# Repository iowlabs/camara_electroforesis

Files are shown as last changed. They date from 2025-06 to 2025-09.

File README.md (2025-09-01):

# Cámara electroforésis

Este proyecto tiene como objetivo el diseño de una cámara de electroforesis de bajo costo y fácil acceso, ideal para entornos educativos, laboratorios escolares,  iniciativas de ciencia ciudadana, equipamientos de bajo costo o laboratorios portátiles. El sistema completo incluye tanto la cámara donde se realiza la separación de moléculas como una fuente de poder casera que permite aplicar el voltaje necesario para el experimento.

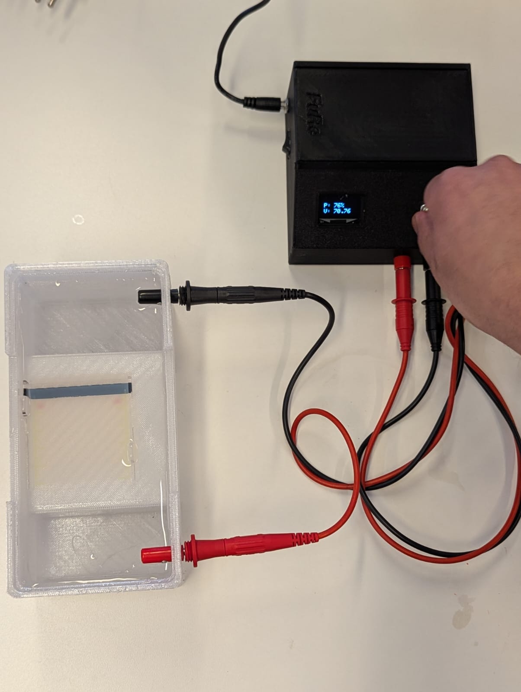
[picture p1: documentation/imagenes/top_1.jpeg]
Cámara de electróforesis


El diseño y la implementación de este proyecto están fuertemente inspirados en la documentación proporcionada por IORodeo, quienes han compartido detalladamente cómo construir sistemas de electroforesis caseros. En particular, se han seguido y adaptado los siguientes recursos:

- [Cámara de electroforesis - Instructables](https://www.instructables.com/Gel-electrophoresis-system-mini/)
- [Fuente de poder - Instructables](https://www.instructables.com/Gel-electrophoresis-power-supply/)

Este repositorio prone un nuevo diseño orientado a consolidar y empaquetar el proceso de fabricación de los componentes por medio de nuevos diseños basados principalmente en impresión 3D. De este modo se consolida la información, archivos de diseño, materiales necesarios y las mejoras propuestas por iow Labs con la intención de facilitar la replicabilidad y su uso por parte de otras personas o instituciones interesadas en el uso de tecnologías abiertas en la ciencia.

---
# Licencias
Todos los archivos involucrados en este proyecto se encuentran bajo licencias abiertas, para su replicabilidad y comercialización.

| Tipo de archivo | Licencia |
| --- |  ----- |
| Electronica 	  |  CERN-OHL-S-2.0 |
| Software y firmware |  GPL-3.0-or-later|
| Diseños 3D |  CERN-OHL-S-2.0 |
| Archivos de documentación | CC-BY-SA-4.0 |

---

# Cámara

En este diseño se propone un modelo de cámara impreso totalmente, como una pieza continua. De este modo, se facilita el proceso de fabricación evitando trabajar con acrílico y las complicaciones que esto implica.

## Materiales

Los tanques para la electróforesis habitualmente se fabrican con acrílico, sin embargo el proceso de cortado y pegado suele ser dificil de gestionar ya que requiere habilidades manuales princilamnte debido a que involucra la manipulación de cloroformo.

Para evitar esto, se implementó una alternativa basada en impresión 3D. Para replicar las características del acrílico se evaluaron diferentes materialidades y metodologías. Finalmente, se optó por imprimir el cuerpo del tanque en PETG para garantizar el buen desempeño en altas temperaturas y para garantizar la impermeabilidad, se optó por aplicarle una capa de resina epoxyca al interior. La tapa se realiza en un solo corte acrílico, para garantizar la transparencia.   

| Pieza 	| Material | Archivo |
| --- | --- | --- |
| Tanque 	|  PETG | [tanque_V2.stl](https://github.com/iowlabs/camara_electroforesis/blob/main/3d%20models/tank_v2.stl) |
| Tapa		| Acrílico | [tapa_V2.stl](https://github.com/iowlabs/camara_electroforesis/blob/main/3d%20models/tapa_v2.stl) |

### Instrucciones de fabricación

## Lista de materiales

| N | Componente 	| Cantidad | Comentario |
|---|---|---|---|
| 1 | Tanque |  1 | |
| 2 | Tapa |  1 | |
| 3 | Conectores banana |  2 | Tipo macho |
| 4 | Electrodos de pt |  2 | arpox 20cm de cable de 0.01'' de platino |

## Instrucciones de armado

---

# Fuente de poder

Para implementar la fuente se diseñó una PCB que integre los componentes considerando en su mayoría componentes SMD. Esta PCB consiste en la implementación de un conversor DC/DC del tipo chopper bust. Este diseño se basa en el integrado MAX117 y la topología utilizada se encuentra detallada en los siguientes documentos 3,4,5
Esta topología es utilizada ampliamente por diferentes proyectos como el Open Drop o la misma fuente de electroforesis de IORodeo. Adicionalmente se consideró agregar un microcontrolador de la familia ESP32S3 para agregar nuevas funcionalidades al diseño y poder considerar en una implementación futura las capacidades de conectividad para montar  una red Lab on a Web que permita controlar todo el laboratorio de forma centralizada y remota.

El esquemático completo se entrega en la siguiente imagen.

Esquemático de la PCB

A continuación se entregan imágenes de las visualizaciones 3D del render de la PCB

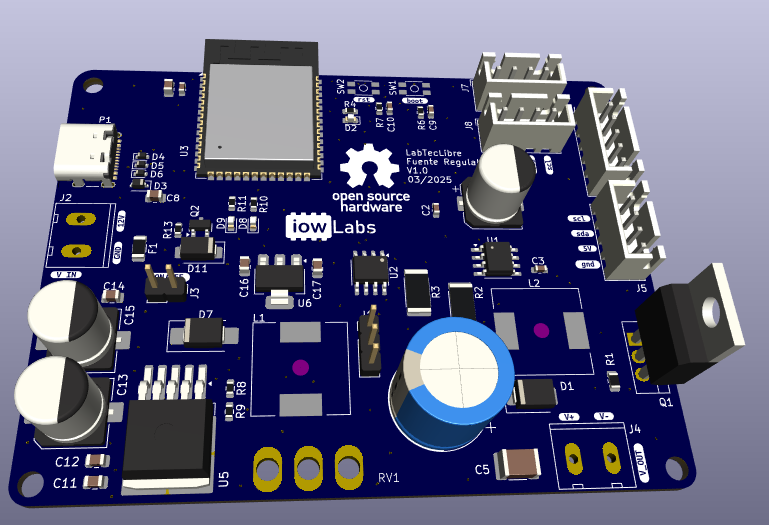
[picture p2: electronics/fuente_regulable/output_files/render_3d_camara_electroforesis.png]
PCB 3D


La PCB considera la integración de una interfaz de usuario implementada por medio de un rotary switch y una pantalla OLED con el objetivo de visualizar el valor actual de voltaje de salida.

Para integrar todos los componentes de forma segura se ha diseñado un casing 3D impreso en PLA.

### Archivos de fabricación
Los archivos de fabricación de la PCB se encuentran disponibles en formato ZIP en el directorio de [archivos de salida](https://github.com/iowlabs/camara_electroforesis/tree/main/electronics/fuente_regulable/output_files) listos para ser enviados a fabricación.

Para el casing, los archivos se encuentran en la carpeta de modelos 3D.

| Pieza 	| Material | Archivo |
| --- | --- | --- |
| Tapa superior 	|  PLA | [fure_tapa.step](https://github.com/iowlabs/camara_electroforesis/blob/main/3d%20models/fure_tapa.step) |
| Cara frontal		| PLA | [fure_cara.step](https://github.com/iowlabs/camara_electroforesis/blob/main/3d%20models/fure_cara.step) |
|  Base		| PLA | [fure_base.step](https://github.com/iowlabs/camara_electroforesis/blob/main/3d%20models/fure_base.step) |

### BOM de PCB
La lista de los componentes se encuentra disponible en el archivo BOM  [fuente_regulable_bom.csv](https://github.com/iowlabs/camara_electroforesis/blob/main/electronics/fuente_regulable/output_files/fuente_regulable_bom.csv), como referencia se consideran de LCSC.

### Lista de materiales para la fuente regulable.

| N | Componente 	| Cantidad | Comentario |
|---|---|---|---|
| 1 | FuRe PCB |  1 | PCB by iow Labs |
| 2 | Conectores banana|  2 |  Tipo hembra  |
| 3 | Cables banana |  2 | Tipo macho - hembra |
| 4 | Switch on/off |  1 |  |
| 5 | Rotary encoder switch |  1 |  |
| 6 | Jack DC |  1 |  |
| 7 | Pantalla OLED |  1 |  |
| 8 | case - superior |  1 | Pieza impresa |
| 9 | case - frontal |  1 | Pieza impresa |
| 10 | case - base |  1 | Pieza impresa |
| 11 | Fuente de 12V |  1 | Al menos 1A (12W) |
| 12 | Tornillos M3 |  6 | Al menos 12mm |
| 13 | Tuercas M3 |  4 | |
| 14 | Cable AWG 20 |  - | Para conexiones internas |
| 15 | Cable AWG 26 - 4 wires |  1 | Cable de la pantalla OLED |
| 16 | Cable AWG 26 - 5 wires |  1 | Cable del rotary encoder |

### Firmware

El firmware se puede encontrar en el directorio [firmware](https://github.com/iowlabs/camara_electroforesis/tree/main/firmware). Esta escrito en el framwork de arduino. Para cargarlo correctamente es necesario configurar en el IDE de arduino la placa ESP32-S3. Para esto se puede usar el modelo ESP32-S3-DEV-Kit.

El código subido implementa una interfaz sencilla entre el rotary encoder y el voltaje de salida que se configura en el módulo MAX117 por medio de un potenciomentro digital configurado por SPI.

Todas las bibliotecas utilizadas se encuentran dentro del repositorio oficial de arduino.

## Instrucciones de ensamblado

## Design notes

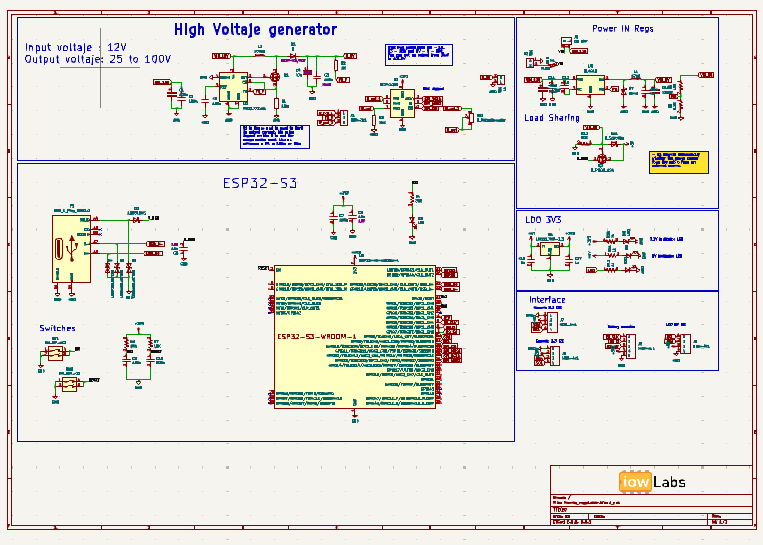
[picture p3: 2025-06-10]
electronics/fuente_regulable/output_files/fuente_electroforesis_esquematico.png

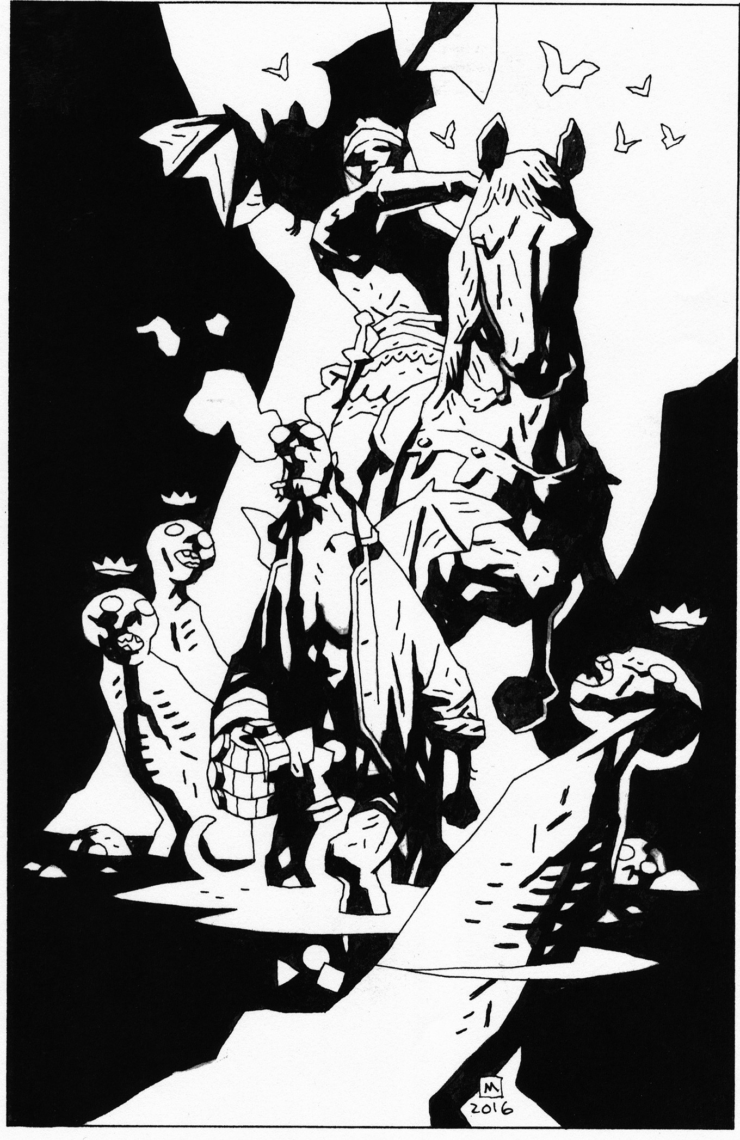
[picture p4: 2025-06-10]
mike-mignola-artwork-thought.jpg

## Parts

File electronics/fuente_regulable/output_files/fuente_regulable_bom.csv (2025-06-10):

Reference | Value | Footprint | Qty | DNP
C1 | 100u | Capacitor_SMD:C_1206_3216Metric | 1 | 5 |  | C445063
C2,C3,C7,C9,C10 | 100n | Capacitor_SMD:C_0603_1608Metric | 5 | 25 |  | C1591
C4 | 47u | Capacitor_SMD:C_1206_3216Metric | 1 | 5 |  | C2837971
C5 | 100n | Capacitor_SMD:C_1812_4532Metric | 1 | 5 |  | C106148
C6,C8 | 10u | Capacitor_SMD:C_0805_2012Metric | 2 | 10 |  | C386019
C11,C12,C14,C16,C17 | 1u | Capacitor_SMD:C_0805_2012Metric | 5 | 25 |  | C215803
C13 | 220uF | Capacitor_SMD:CP_Elec_8x10.5 | 1 | 5 |  | C3353
C15 | 330uF | Capacitor_SMD:CP_Elec_8x10.5 | 1 | 5 |  | C3353
D1 | D | Diode_SMD:D_SMB | 1 | 5 |  | C145321
D2,D8,D9,D10 | LED | LED_SMD:LED_0603_1608Metric | 4 | 20
D3 | 1N5819WS | Diode_SMD:D_SOD-323 | 1 | 5 |  | C82544
D4,D5,D6 | LESD5D5.0CT1G | Diode_SMD:D_SOD-523 | 3 | 15 | 637-ESD5B5V0WT | C5246195
D7 | B540 | Diode_SMD:D_SMB_Handsoldering | 1 | 5 | 750-ACDBB540-HF | C3019736
D11 | D_Schottky | Diode_SMD:D_SMA | 1 | 5 |  | C85098
F1 | FUSE | Fuse:Fuse_1206_3216Metric | 1 | 5 |  | C41367231
J1 | HDR-3x1 | Connector_JST:JST_XH_B4B-XH-A_1x04_P2.50mm_Vertical | 1 | 5
J2,J4 | VIN | IoWLabsConnectors:Tb-2x1-5p-TH-V | 2 | 10
J3 | ON OFF | Connector_PinHeader_2.54mm:PinHeader_1x02_P2.54mm_Vertical | 1 | 5
J5,J7,J8 | HDR-4x1 | Connector_JST:JST_XH_B4B-XH-A_1x04_P2.50mm_Vertical | 3 | 15
J6 | HDR-5x1 | Connector_JST:JST_XH_B5B-XH-A_1x05_P2.50mm_Vertical | 1 | 5
L1 | 47uH | Inductor_SMD:L_12x12mm_H8mm | 1 | 5 |  | C2929502
L2 | 100uH | Inductor_SMD:L_12x12mm_H8mm | 1 | 5 |  | C7431084
P1 | USB_C_Plug_USB2.0 | Connector_USB:USB_C_Receptacle_GCT_USB4105-xx-A_16P_TopMnt_Horizontal | 1 | 5 | 179-UJ20CHC4SMTTR | C165948
Q1 | Q_NMOS_Depletion_GDS | Package_TO_SOT_SMD:TO-220 | 1 | 5 |  | C34373758
Q2 | Q_PMOS_GSD | Package_TO_SOT_SMD:SOT-23 | 1 | 5 | 512-FDN338P | C518789
R1 | 10m | Resistor_SMD:R_2512_6332Metric | 1 | 5 |  | C2934081
R2 | 1M | Resistor_SMD:R_2512_6332Metric | 1 | 5 |  | C346106
R3 | 15K | Resistor_SMD:R_2512_6332Metric | 1 | 5 |  | C5200562
R4 | 330 | Resistor_SMD:R_0603_1608Metric | 1 | 5
R6,R7,R8,R13 | 10K | Resistor_SMD:R_0603_1608Metric | 4 | 20
R9 | 3.3K | Resistor_SMD:R_0603_1608Metric | 1 | 5 |  | C309653
R10,R11,R12 | 1k | Resistor_SMD:R_0603_1608Metric | 3 | 15
RV1 | R_Potentiometer | IoWLabs:PDB18 - Rotary Potentiometer | 1 | 5
SW1,SW2 | SW_DIP_x02 | IoWLabs:SMD_SWITCH | 2 | 10 | 688-SKTHACE010 | C128941
U1 | MAX1771xSA | Package_SO:SO-8_3.9x4.9mm_P1.27mm | 1 | 5 | 700-MAX1771CSAT | C407903
U2 | MCP41050 | Package_SO:SOIC-8_3.9x4.9mm_P1.27mm | 1 | 5 | 579-MCP41050-I/SN | C124138
U3 | ESP32-S3-WROOM-1 | RF_Module:ESP32-S3-WROOM-1 | 1 | 5 | 356-ESP32-S3WROOM1N8 | C2913205
U5 | XL4015 | Package_TO_SOT_SMD:TO-263-5_TabPin3 | 1 | 5 |  | C51661
U6 | AP2112K-3.3 | Package_TO_SOT_SMD:SOT-23-5 | 1 | 5 |  | C129334

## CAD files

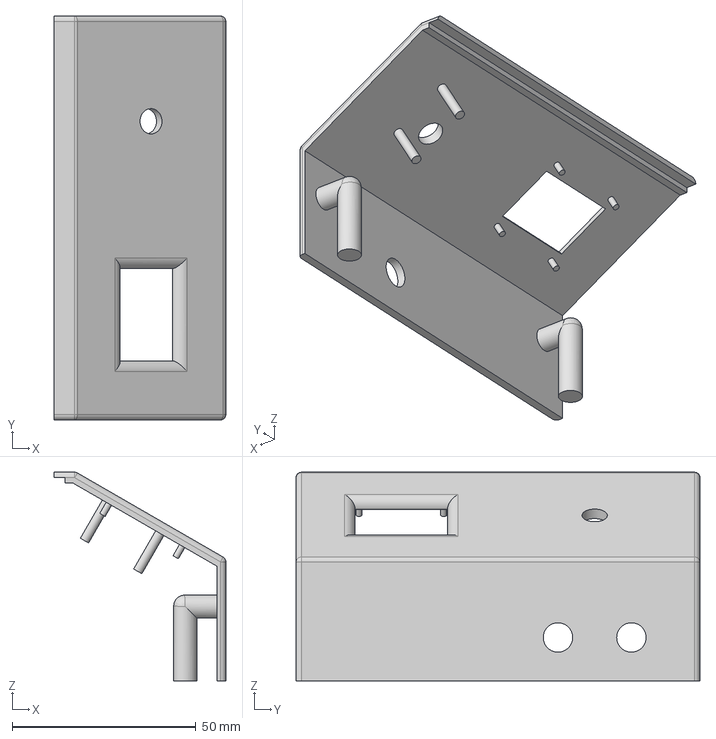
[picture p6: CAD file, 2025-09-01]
3d models/fure_cara.step
46.8 x 110.0 x 56.8 mm

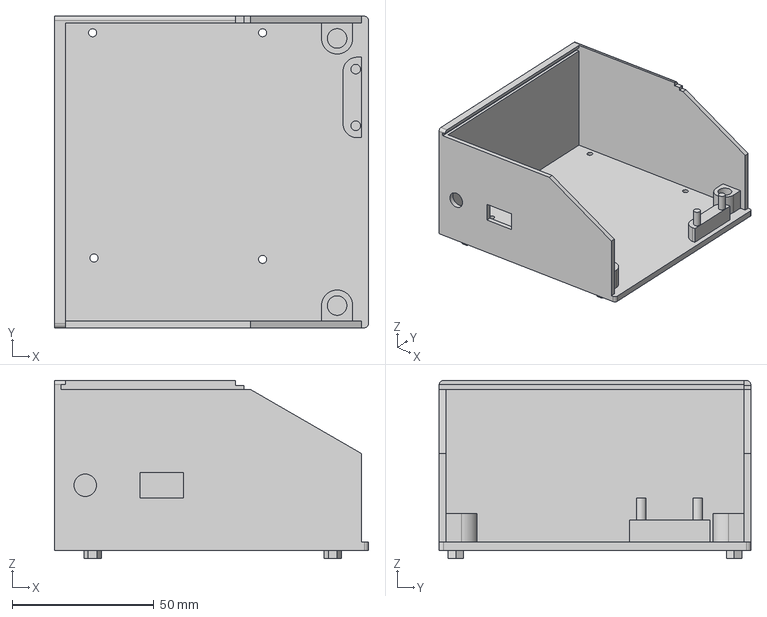
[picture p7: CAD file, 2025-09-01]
3d models/fure_base.step
110.9 x 110.0 x 62.9 mm

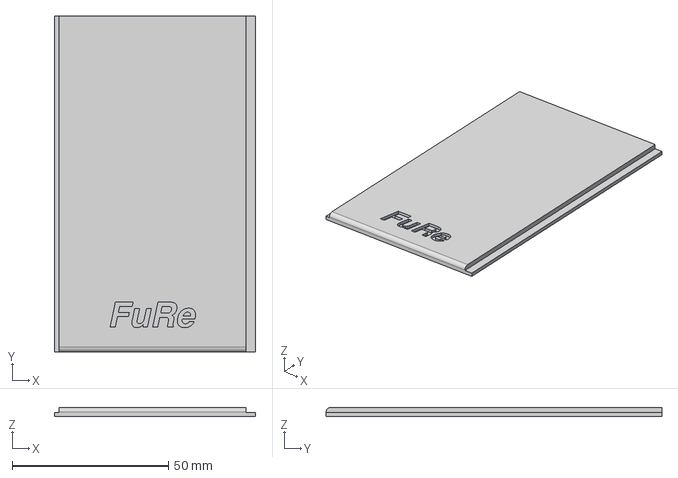
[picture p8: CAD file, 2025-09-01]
3d models/fure_tapa.step
64.3 x 107.5 x 3.00 mm

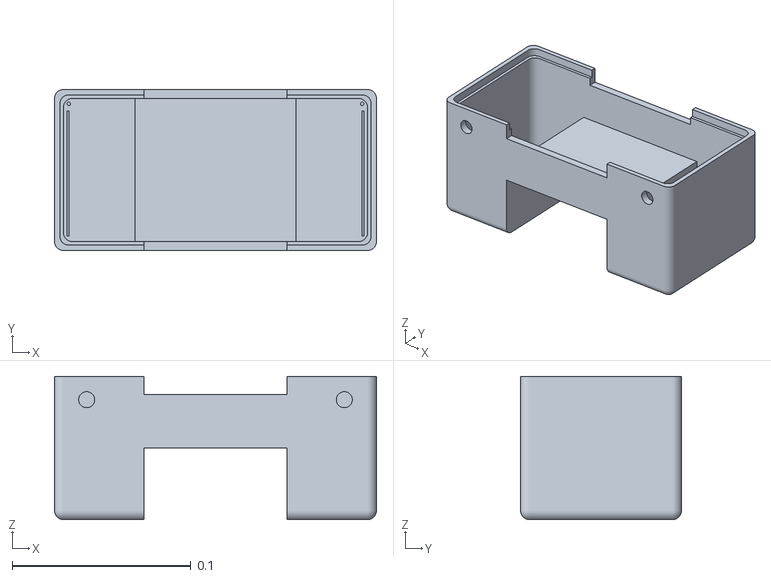
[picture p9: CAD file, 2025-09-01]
3d models/tank_v2.stl
0.18 x 0.09 x 0.08

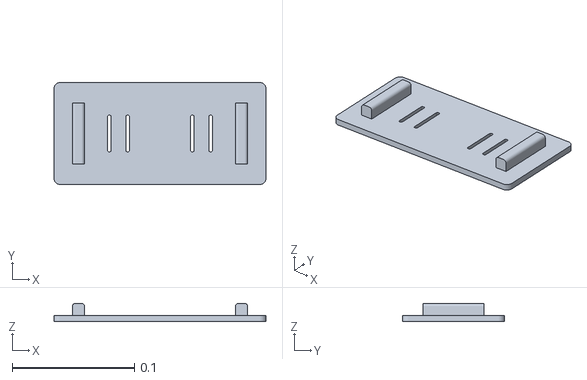
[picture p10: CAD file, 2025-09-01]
3d models/tapa_v2.stl
0.174 x 0.0835 x 0.015

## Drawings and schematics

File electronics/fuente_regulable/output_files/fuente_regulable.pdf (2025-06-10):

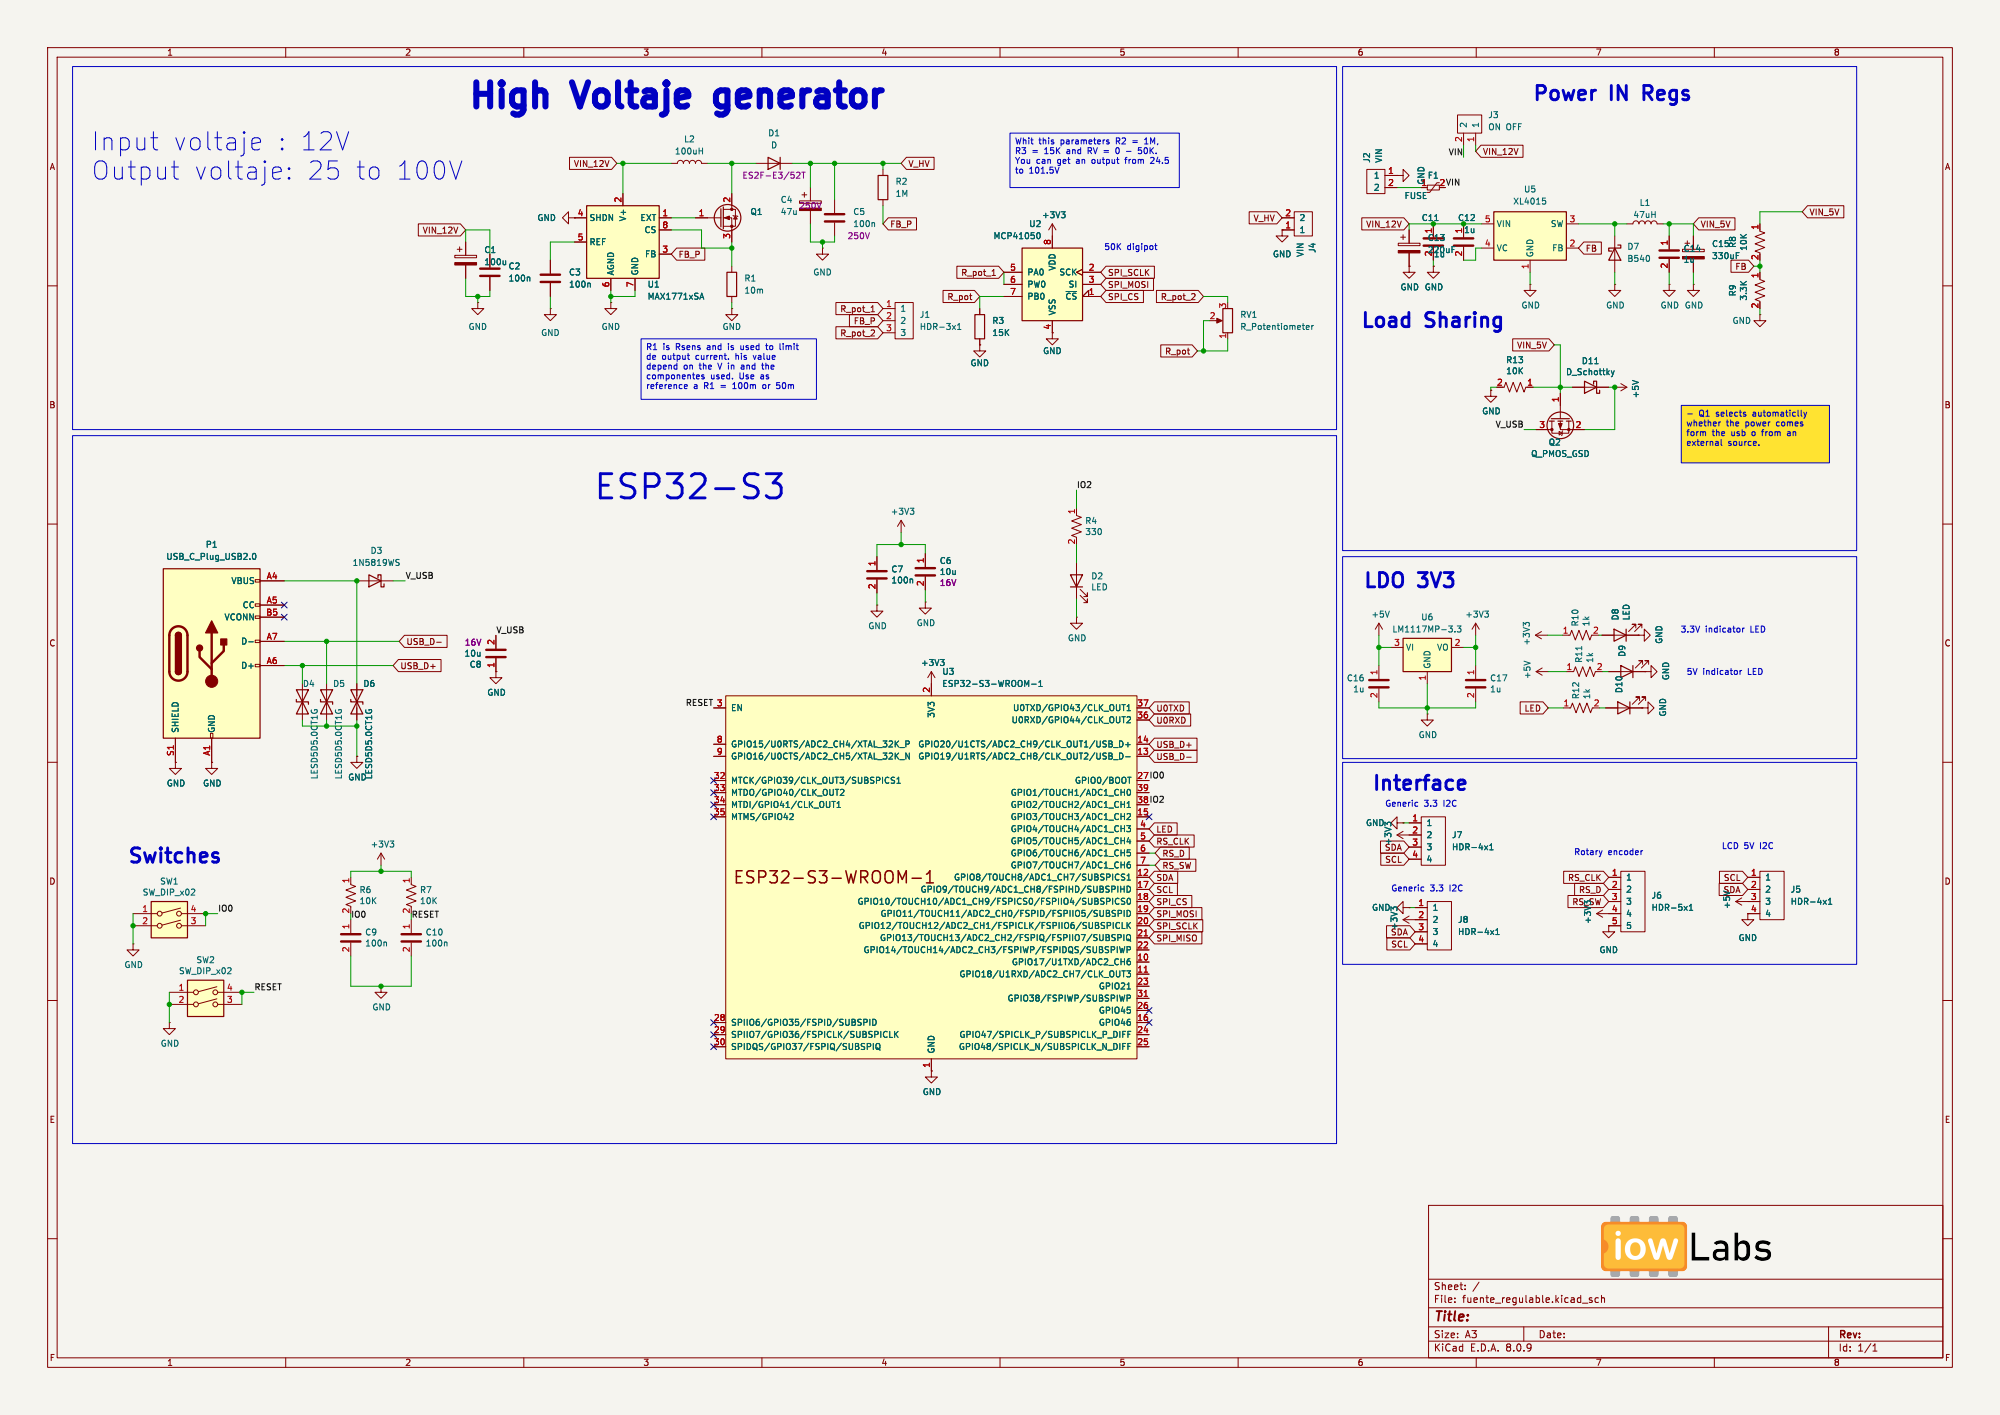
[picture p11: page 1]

1 FB 2 SW 3 VC 4 VIN 5 U5 XL4015

2 FB 3 SHDN 4 REF 5 AGND

depend on the V in and the

- Q1 selects automaticlly whether the power comes

form the usb o from an

1 2 P1 USB_C_Plug_USB2.0 GND A1 VBUS A4 CC A5 D+ A6 D- A7 VCONN B5 SHIELD S1

2 GPIO12/TOUCH12/ADC2_CH1/FSPICLK/FSPIIO6/SUBSPICLK 20 GPIO13/TOUCH13/ADC2_CH2/FSPIQ/FSPIIO7/SUBSPIQ 21 GPIO14/TOUCH14/ADC2_CH3/FSPIWP/FSPIDQS/SUBSPIWP 22 GPIO21 23 GPIO47/SPICLK_P/SUBSPICLK_P_DIFF 24 GPIO48/SPICLK_N/SUBSPICLK_N_DIFF 25 GPIO45 26 GPIO0/BOOT 27 SPIIO6/GPIO35/FSPID/SUBSPID 28 SPIIO7/GPIO36/FSPICLK/SUBSPICLK 29 EN 3 SPIDQS/GPIO37/FSPIQ/SUBSPIQ 30 GPIO38/FSPIWP/SUBSPIWP 31 MTCK/GPIO39/CLK_OUT3/SUBSPICS1 32 MTDO/GPIO40/CLK_OUT2 33 MTDI/GPIO41/CLK_OUT1 34 MTMS/GPIO42 35 U0RXD/GPIO44/CLK_OUT2 36 U0TXD/GPIO43/CLK_OUT1 37 GPIO2/TOUCH2/ADC1_CH1 38 GPIO1/TOUCH1/ADC1_CH0 39 GPIO4/TOUCH4/ADC1_CH3 4 GPIO5/TOUCH5/ADC1_CH4 5 GPIO6/TOUCH6/ADC1_CH5 6 GPIO7/TOUCH7/ADC1_CH6 7 GPIO15/U0RTS/ADC2_CH4/XTAL_32K_P 8 GPIO16/U0CTS/ADC2_CH5/XTAL_32K_N 9 U3ESP32-S3-WROOM-1 +3V3 GND GND

2 GPIO12/TOUCH12/ADC2_CH1/FSPICLK/FSPIIO6/SUBSPICLK 20 GPIO13/TOUCH13/ADC2_CH2/FSPIQ/FSPIIO7/SUBSPIQ 21 GPIO14/TOUCH14/ADC2_CH3/FSPIWP/FSPIDQS/SUBSPIWP 22 GPIO21 23 GPIO47/SPICLK_P/SUBSPICLK_P_DIFF 24 GPIO48/SPICLK_N/SUBSPICLK_N_DIFF 25 GPIO45 26 GPIO0/BOOT 27 SPIIO6/GPIO35/FSPID/SUBSPID 28 SPIIO7/GPIO36/FSPICLK/SUBSPICLK 29 EN 3 SPIDQS/GPIO37/FSPIQ/SUBSPIQ 30 GPIO38/FSPIWP/SUBSPIWP 31 MTCK/GPIO39/CLK_OUT3/SUBSPICS1 32 MTDO/GPIO40/CLK_OUT2 33 MTDI/GPIO41/CLK_OUT1 34 MTMS/GPIO42 35 U0RXD/GPIO44/CLK_OUT2 36 U0TXD/GPIO43/CLK_OUT1 37 GPIO2/TOUCH2/ADC1_CH1 38 GPIO1/TOUCH1/ADC1_CH0 39 GPIO4/TOUCH4/ADC1_CH3 4 GPIO5/TOUCH5/ADC1_CH4 5 GPIO6/TOUCH6/ADC1_CH5 6 GPIO7/TOUCH7/ADC1_CH6 7 GPIO15/U0RTS/ADC2_CH4/XTAL_32K_P 8 GPIO16/U0CTS/ADC2_CH5/XTAL_32K_N 9 +3V3 GND

1 GPIO17/U1TXD/ADC2_CH6 10 GPIO18/U1RXD/ADC2_CH7/CLK_OUT3 11 GPIO8/TOUCH8/ADC1_CH7/SUBSPICS1 12 GPIO19/U1RTS/ADC2_CH8/CLK_OUT2/USB_D- 13 GPIO20/U1CTS/ADC2_CH9/CLK_OUT1/USB_D+ 14 GPIO3/TOUCH3/ADC1_CH2 15 GPIO46 16 GPIO9/TOUCH9/ADC1_CH8/FSPIHD/SUBSPIHD 17 GPIO10/TOUCH10/ADC1_CH9/FSPICS0/FSPIIO4/SUBSPICS0 18 GPIO11/TOUCH11/ADC2_CH0/FSPID/FSPIIO5/SUBSPID 19 3V3

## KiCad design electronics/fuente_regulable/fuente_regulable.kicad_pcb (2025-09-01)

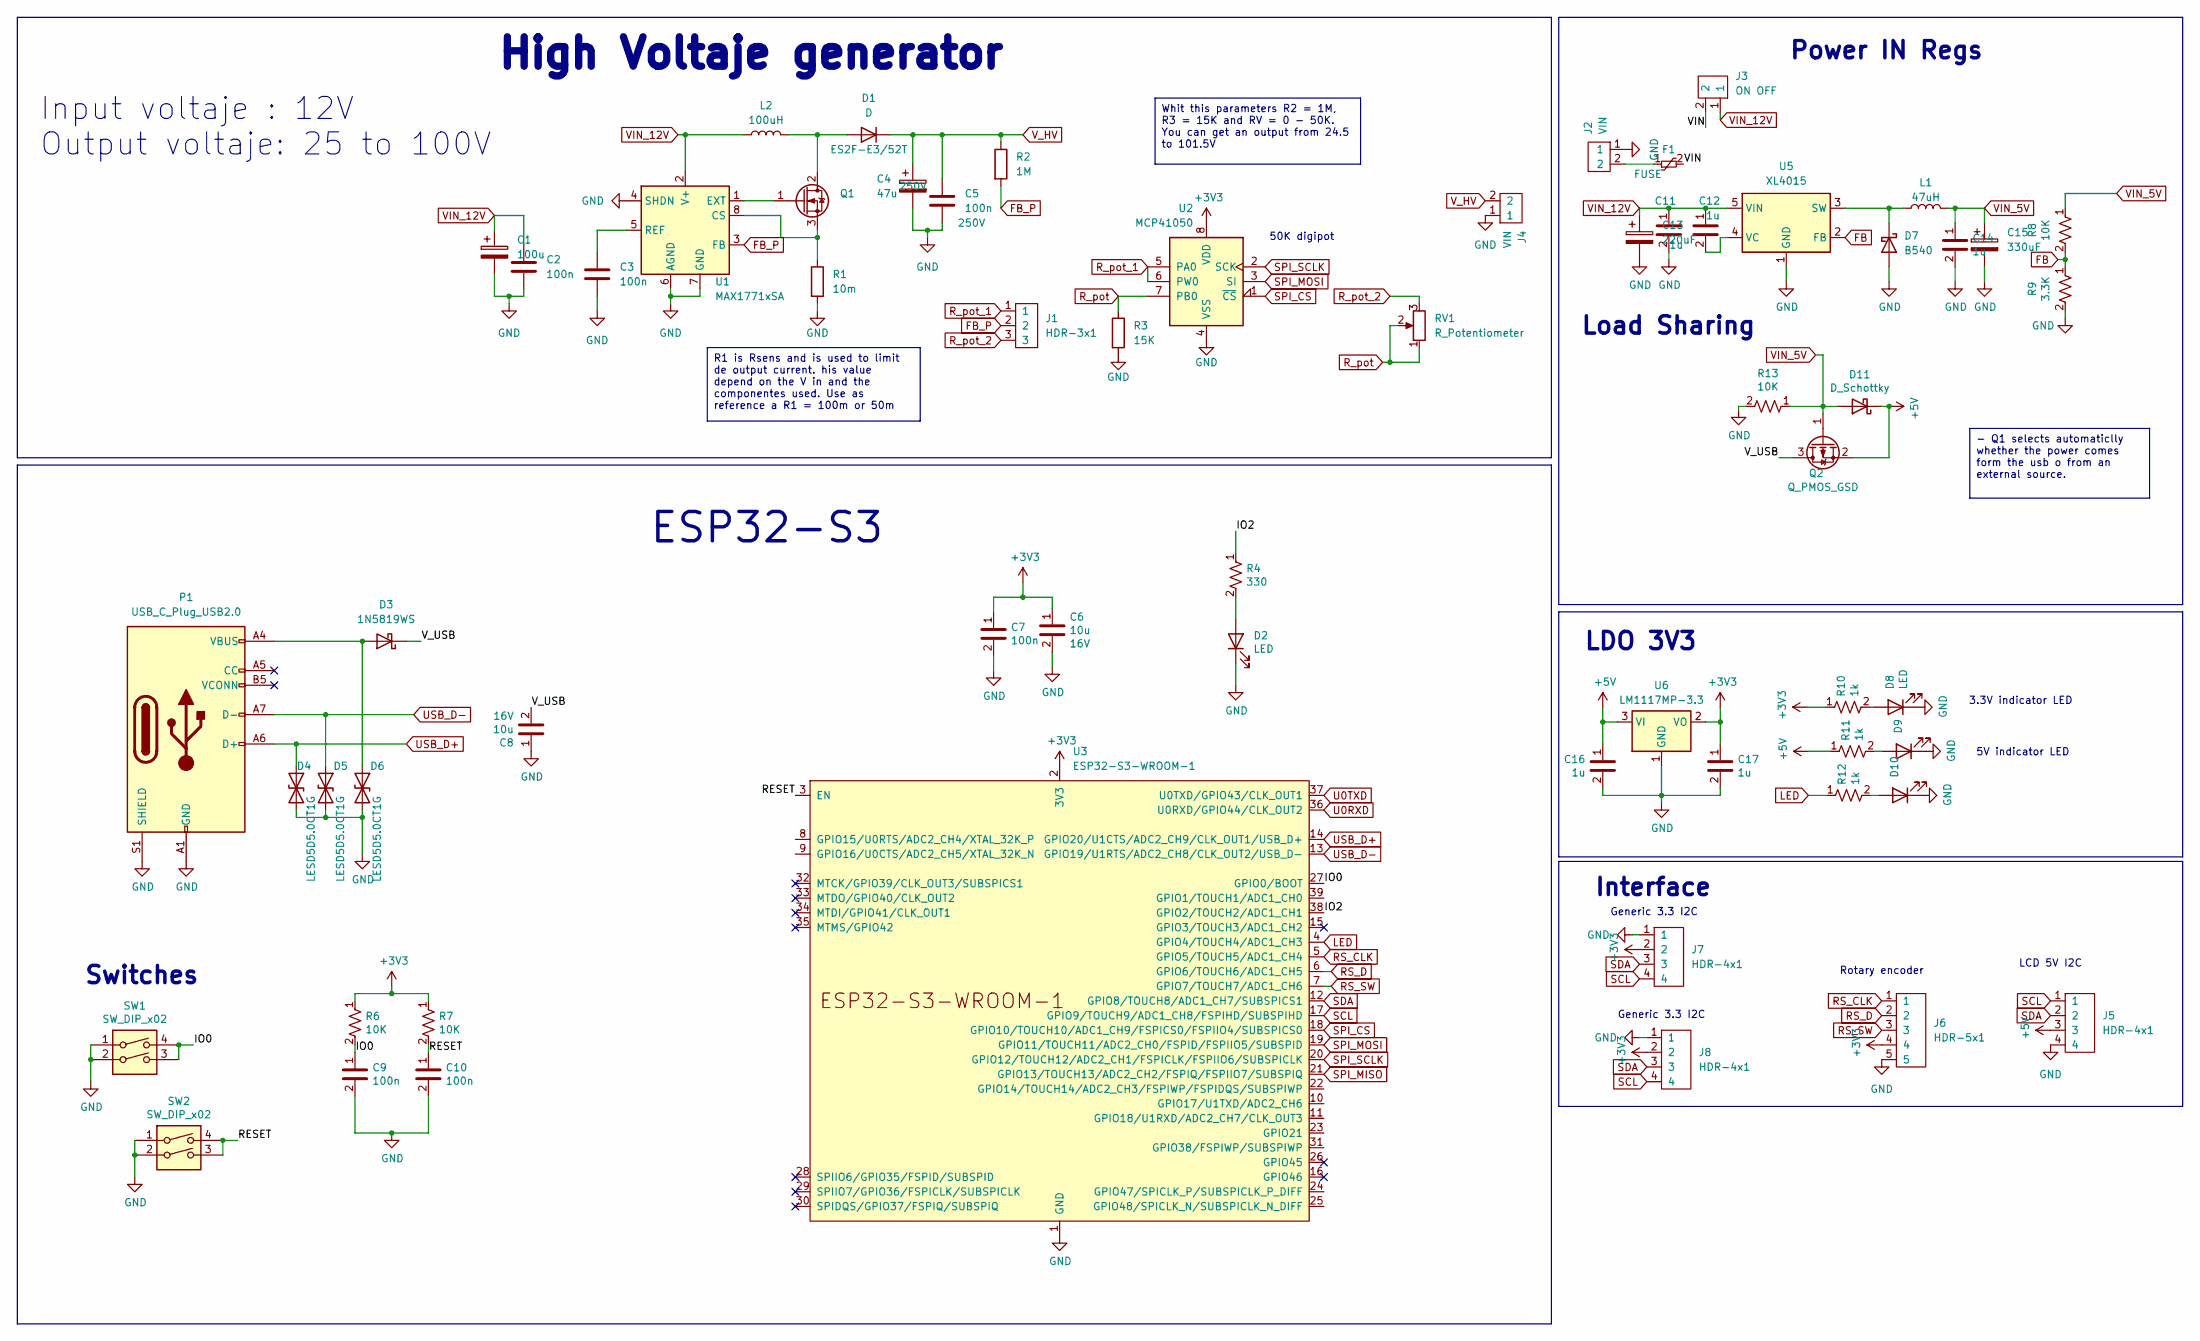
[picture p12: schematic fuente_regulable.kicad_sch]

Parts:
C1: 100u; CP_Elec_8x10
C2, C3: 100n; C_0603_1608Metric
C4: 47u; CP_Radial_D13.0mm_P5.00mm
C5: 100n; C_1812_4532Metric
C6, C8: 10u; C_0805_2012Metric; Voltage rated 16V
C7, C9, C10: 100n; C_0603_1608Metric; Voltage rated 16V
C11, C12, C14, C16, C17: 1u; C_0805_2012Metric; Voltage rated 16V
C13: 220uF; CP_Elec_8x10.5; Voltage 50V
C15: 330uF; CP_Elec_8x10.5; Voltage 25V
D1: D; D_SMB
D2, D8, D9, D10: LED; LED_0603_1608Metric
D3: 1N5819WS; D_SOD-323
D4, D5, D6: LESD5D5.0CT1G; D_SOD-523
D7: B540; D_SMB_Handsoldering
D11: D_Schottky; D_SMA
F1: FUSE; Fuse_1206_3216Metric
J1: HDR-3x1; PinHeader_1x03_P2.54mm_Vertical
J2, J4: VIN; Tb-2x1-5p-TH-V
J3: ON OFF; PinHeader_1x02_P2.54mm_Vertical
J5, J7, J8: HDR-4x1; JST_XH_B4B-XH-A_1x04_P2.50mm_Vertical
J6: HDR-5x1; JST_XH_B5B-XH-A_1x05_P2.50mm_Vertical
L1: 47uH; L_12x12mm_H8mm
L2: 100uH; L_12x12mm_H6mm
P1: USB_C_Plug_USB2.0; USB_C_Receptacle_GCT_USB4105-xx-A_16P_TopMnt_Horizontal
Q1: Q_NMOS_Depletion_GDS; TO-220-3_Vertical
Q2: Q_PMOS_GSD; SOT-23
R1: 10m; R_0805_2012Metric
R2: 1M; R_2512_6332Metric
R3: 15K; R_2512_6332Metric
R4: 330; R_0603_1608Metric
R6, R7, R8, R13: 10K; R_0603_1608Metric
R9: 3.3K; R_0603_1608Metric
R10, R11, R12: 1k; R_0603_1608Metric
RV1: R_Potentiometer; PDB18 - Rotary Potentiometer
SW1, SW2: SW_DIP_x02; SMD_SWITCH
U1: MAX1771xSA; SO-8_3.9x4.9mm_P1.27mm
U2: MCP41050; SOIC-8_3.9x4.9mm_P1.27mm
U3: ESP32-S3-WROOM-1
U5: XL4015; TO-263-5_TabPin3
U6: LM1117MP-3.3; SOT-223-3_TabPin2

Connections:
+3V3: C6.1, C7.1, C17.1, J6.4, J7.2, J8.2, R6.1, R7.1, R10.1, U2.8 (VDD), U3.2 (3V3), U6.2 (VO)
+5V: C16.1, D11.1 (K), J5.3, Q2.2 (S), R11.1, U6.3 (VI)
/IO0: C9.1, R6.2, SW1.3, SW1.4, U3.27 (GPIO0/BOOT)
/IO2: R4.1, U3.38 (GPIO2/TOUCH2/ADC1_CH1)
/RESET: C10.1, R7.2, SW2.3, SW2.4, U3.3 (EN)
/VIN: F1.2, J3.2
/V_USB: C8.2, D3.1 (K), Q2.3 (D)
FB: R8.2, R9.1, U5.2 (FB)
FB_P: J1.2, R2.2, U1.3 (FB)
GND: C1.2, C2.2, C3.2, C4.2, C5.2, C6.2, C7.2, C8.1, C9.2, C10.2, C11.2, C13.2, C14.2, C15.2, C16.2, C17.2, D2.1 (K), D4.2 (A2), D5.2 (A2), D6.2 (A2), D7.2 (A), D8.1 (K), D9.1 (K), D10.1 (K), J2.1, J4.1, J5.4, J6.5, J7.1, J8.1, P1.A1 (GND), P1.A12 (GND), P1.B1 (GND), P1.B12 (GND), P1.S1 (SHIELD), R1.2, R3.2, R9.2, R13.2, SW1.1, SW1.2, SW2.1, SW2.2, U1.4 (SHDN), U1.6 (AGND), U1.7 (GND), U2.4 (VSS), U3.1 (GND), U3.40 (GND), U3.41 (GND), U5.1 (GND), U6.1 (GND)
LED: R12.1, U3.4 (GPIO4/TOUCH4/ADC1_CH3)
unnamed: D1.2 (A), L2.2, Q1.2 (D)
unnamed: D2.2 (A), R4.2
unnamed: D3.2 (A), D6.1 (A1), P1.A4 (VBUS), P1.A9 (VBUS), P1.B4 (VBUS), P1.B9 (VBUS)
unnamed: D7.1 (K), L1.1, U5.3 (SW)
unnamed: D8.2 (A), R10.2
unnamed: D9.2 (A), R11.2
unnamed: D10.2 (A), R12.2
unnamed: F1.1, J2.2
unnamed: Q1.1 (G), U1.1 (EXT)
unnamed: Q1.3 (S), R1.1, U1.8 (CS)
unnamed: C3.1, U1.5 (REF)
unnamed: C12.2, U5.4 (VC)
RS_CLK: J6.1, U3.5 (GPIO5/TOUCH5/ADC1_CH4)
RS_D: J6.2, U3.6 (GPIO6/TOUCH6/ADC1_CH5)
RS_SW: J6.3, U3.7 (GPIO7/TOUCH7/ADC1_CH6)
R_pot: R3.1, RV1.1, RV1.2, U2.7 (PB0)
R_pot_1: J1.1, U2.5 (PA0), U2.6 (PW0)
R_pot_2: J1.3, RV1.3
SCL: J5.1, J7.4, J8.4, U3.17 (GPIO9/TOUCH9/ADC1_CH8/FSPIHD/SUBSPIHD)
SDA: J5.2, J7.3, J8.3, U3.12 (GPIO8/TOUCH8/ADC1_CH7/SUBSPICS1)
SPI_CS: U2.1 (~CS), U3.18 (GPIO10/TOUCH10/ADC1_CH9/FSPICS0/FSPIIO4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)
SPI_MISO: U3.21 (GPIO13/TOUCH13/ADC2_CH2/FSPIQ/FSPIIO7/S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)
SPI_MOSI: U2.3 (SI), U3.19 (GPIO11/TOUCH11/ADC2_CH0/FSPID/FSPIIO5/S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)
SPI_SCLK: U2.2 (SCK), U3.20 (GPIO12/TOUCH12/ADC2_CH1/FSPICLK/FSPIIO6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)
U0RXD: U3.36 (U0RXD/GPIO44/CLK_OUT2)
U0TXD: U3.37 (U0TXD/GPIO43/CLK_OUT1)
USB_D+: D4.1 (A1), P1.A6 (D+), U3.14 (GPIO20/U1CTS/ADC2_CH9/CLK_OUT1/USB_D+)
USB_D-: D5.1 (A1), P1.A7 (D-), U3.13 (GPIO19/U1RTS/ADC2_CH8/CLK_OUT2/USB_D-)
VIN_5V: C14.1, C15.1, D11.2 (A), L1.2, Q2.1 (G), R8.1, R13.1
VIN_12V: C1.1, C2.1, C11.1, C12.1, C13.1, J3.1, L2.1, U1.2 (V+), U5.5 (VIN)
V_HV: C4.1, C5.1, D1.1 (K), J4.2, R2.1

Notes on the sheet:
Whit this parameters R2 = 1M, R3 = 15K and RV = 0 - 50K. You can get an output from 24.5 to 101.5V
- Q1 selects automaticlly whether the power comes form the usb o from an external source.
R1 is Rsens and is used to limit de output current. his value depend on the V in and the componentes used. Use as reference a R1 = 100m or 50m
LCD 5V I2C
High Voltaje generator
3.3V indicator LED
50K digipot
Power IN Regs
Load Sharing
5V indicator LED
Interface
Generic 3.3 I2C
Switches
ESP32-S3
Rotary encoder
LDO 3V3
Input voltaje : 12V Output voltaje: 25 to 100V

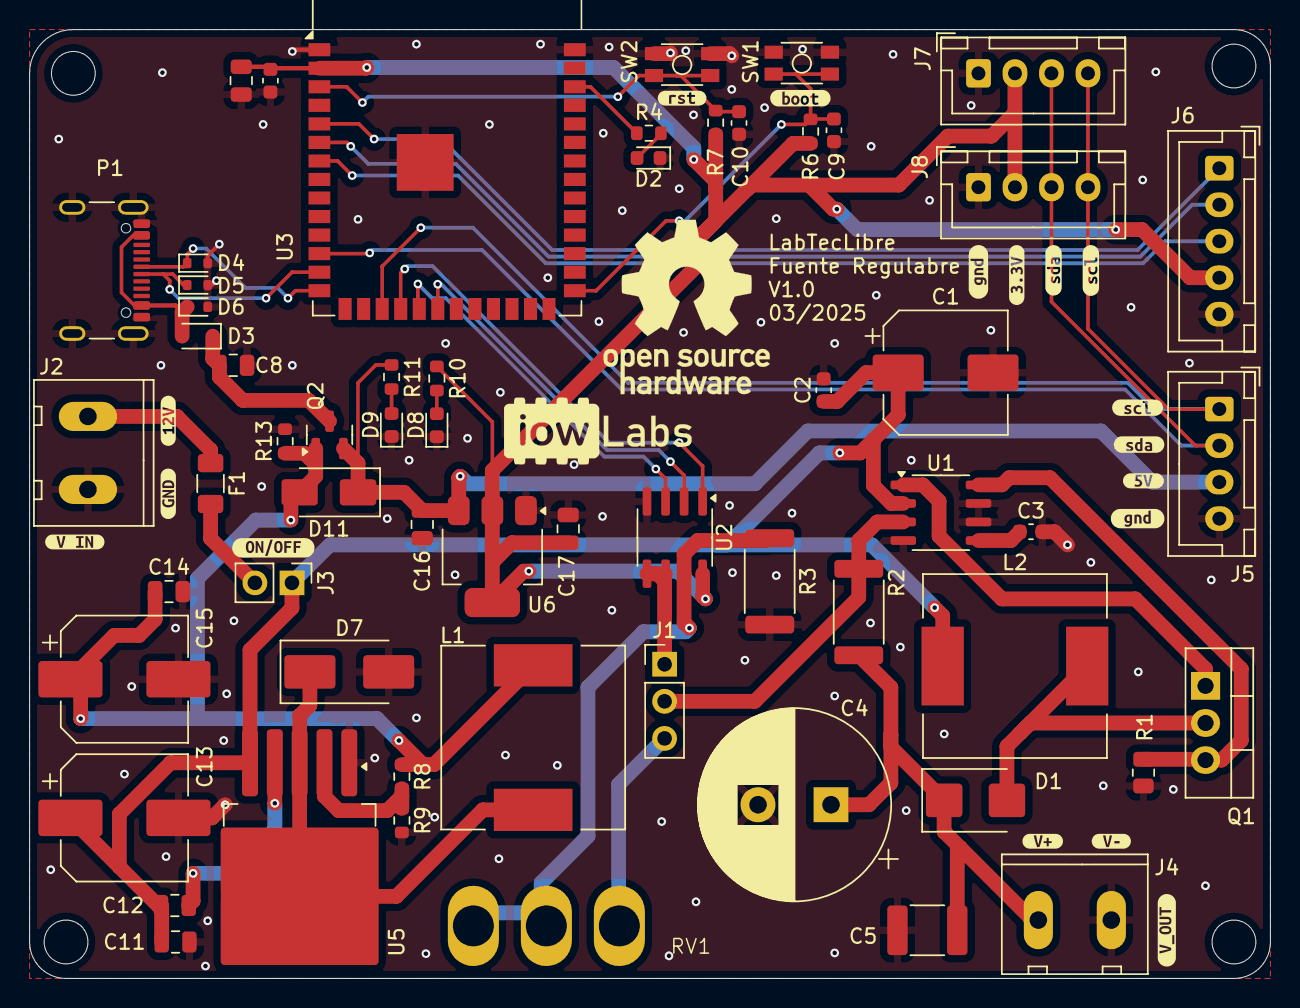
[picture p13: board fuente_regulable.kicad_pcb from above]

Board: 2 copper layers, 85.0 x 65.0 mm, 77 parts (0 on the bottom side), 37 nets.

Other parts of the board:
kibuzzard-67D7A0B2: G***; kibuzzard-67D7A0B2
kibuzzard-67D7A0C2: G***; kibuzzard-67D7A0C2
kibuzzard-67D7A0EB: G***; kibuzzard-67D7A0EB
kibuzzard-67D7A0F3: G***; kibuzzard-67D7A0F3
kibuzzard-67D7A0FE: G***; kibuzzard-67D7A0FE
kibuzzard-67D7A1A6: G***; kibuzzard-67D7A1A6
kibuzzard-67D7A1B2, kibuzzard-67D7A1B2#2: G***; kibuzzard-67D7A1B2
kibuzzard-67D7A14C: G***; kibuzzard-67D7A14C
kibuzzard-67D7A19B, kibuzzard-67D7A19B#2: G***; kibuzzard-67D7A19B
kibuzzard-67D7A27B: G***; kibuzzard-67D7A27B
kibuzzard-67D7A162: G***; kibuzzard-67D7A162
kibuzzard-67D7A185, kibuzzard-67D7A185#2: G***; kibuzzard-67D7A185
kibuzzard-67D7A229: G***; kibuzzard-67D7A229
kibuzzard-67D7A262: G***; kibuzzard-67D7A262

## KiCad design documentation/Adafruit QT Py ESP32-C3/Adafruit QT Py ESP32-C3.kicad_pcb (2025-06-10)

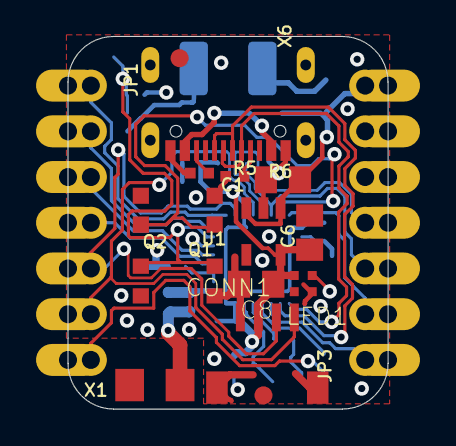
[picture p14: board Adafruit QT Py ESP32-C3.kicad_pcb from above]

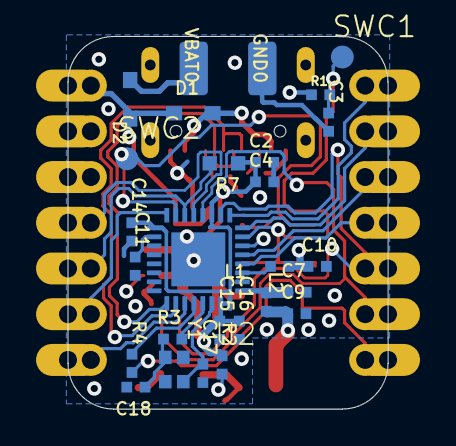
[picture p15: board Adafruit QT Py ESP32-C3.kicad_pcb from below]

Board: 4 copper layers, 17.8 x 20.7 mm, 46 parts (29 on the bottom side), 31 nets.

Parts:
C1, C6, C8: 22uF; 0805-NO
C2, C3, C11, C15: 1uF; _0402NO
C4, C10, C14: 0.1uF; _0402NO
C7, C9: TBD; _0402NO
C16: 0.01uF; _0402NO
C17, C18: 16pF; _0402NO
CONN1: STEMMA_I2C_QTSKINNY; JST_SH4_SKINNY
D1, D2: NSR0320; SOD-323_MINI
GND0: TESTPOINT_MINUS_1X3MM
JP1, JP3: 1X07_CASTEL
L1: 2nH; _0402
L2: 0 ohm; _0402
LED1: WS2812B_SK6805_1515; SK6805_1515
Q1: BOOT0; BTN_KMR2_4.6X2.8
Q2: reset; BTN_KMR2_SLIM
R1, R2: 10K; _0402NO
R3: 0; _0402NO
R4: 1k; _0402NO
R5, R6: 5.1K; _0402NO
R7: 10K; _0603MP_TWO6MIL
SWC1, SWC2: TPB1,27; B1,27_385
U1: AP2112K-3.3; SOT23-5
U2: ESP32-C3FH4; QFN32_5MM
U$3: QTPYC3_TOP
U$6, U$8: FIDUCIAL_1MM
U$12: PCBFEAT-REV-040
U$18: QTPYC3_BOT
VBAT0: TESTPOINT_PLUS_1X3MM
X1: 2.4GHz; ANT_2450AT18B100
X6: USB TYPE C; USB_C_CUSB31-CFM2AX-01-X
Y1: 40MHz; CRYSTAL_2X1.6

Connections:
3.3V: C2.1, C4.1, C6.1, C8.1, C10.1, C14.1, C15.1, C16.1, CONN1.2, JP3.5, JP3.5C, L1.1, LED1.2, R1.1, R2.1, R7.1, U1.5, U2.11, U2.17, U2.31, U2.32
+5V: C1.1, D1.C, D2.C, JP3.7, JP3.7C, U1.1, U1.3
A0: JP1.1, JP1.1C, U2.9
A1: JP1.2, JP1.2C, U2.8
A2: JP1.3, JP1.3C, U2.5
A3: JP1.4, JP1.4C, U2.4
BOOT: Q1.A, Q1.A', SWC2.TP, U2.15
CC1: R6.2, X6.A5
CC2: R5.2, X6.B5
D+: U2.26, X6.A6, X6.B6
D-: U2.25, X6.A7, X6.B7
GND: C1.2, C2.2, C3.2, C4.2, C6.2, C7.2, C8.2, C9.2, C10.2, C11.2, C14.2, C15.2, C16.2, C17.2, C18.2, CONN1.1, CONN1.MT1, CONN1.MT2, GND0.P$1, JP3.6, JP3.6C, LED1.4, Q1.B', Q2.B, Q2.B', R5.1, R6.1, U1.2, U2.33, X6.A1B12, X6.B1A12
LNA: C7.1, L2.2, U2.1
MISO: JP3.3, JP3.3C, R7.2, U2.14
MOSI: JP3.4, JP3.4C, U2.13
unnamed: R4.1, U2.28
unnamed: C9.1, L2.1, X1.FP
unnamed: R3.2, U2.29
unnamed: C17.1, U2.30, Y1.3
unnamed: C18.1, R3.1, Y1.1
NEOPIX: LED1.1, R2.2, U2.6
RX: JP3.1, JP3.1C, U2.27
SCK: JP3.2, JP3.2C, U2.16
SCL: CONN1.4, JP1.6, JP1.6C, U2.12
SDA: CONN1.3, JP1.5, JP1.5C, U2.10
TX: JP1.7, JP1.7C, R4.2
VBAT: D2.A, VBAT0.P$1
VBUS: D1.A, X6.A4B9, X6.B4A9
VDD3P3: L1.2, U2.2, U2.3
VDD_SPI: C11.1, U2.18
~RESET: C3.1, Q2.A, Q2.A', R1.2, SWC1.TP, U2.7

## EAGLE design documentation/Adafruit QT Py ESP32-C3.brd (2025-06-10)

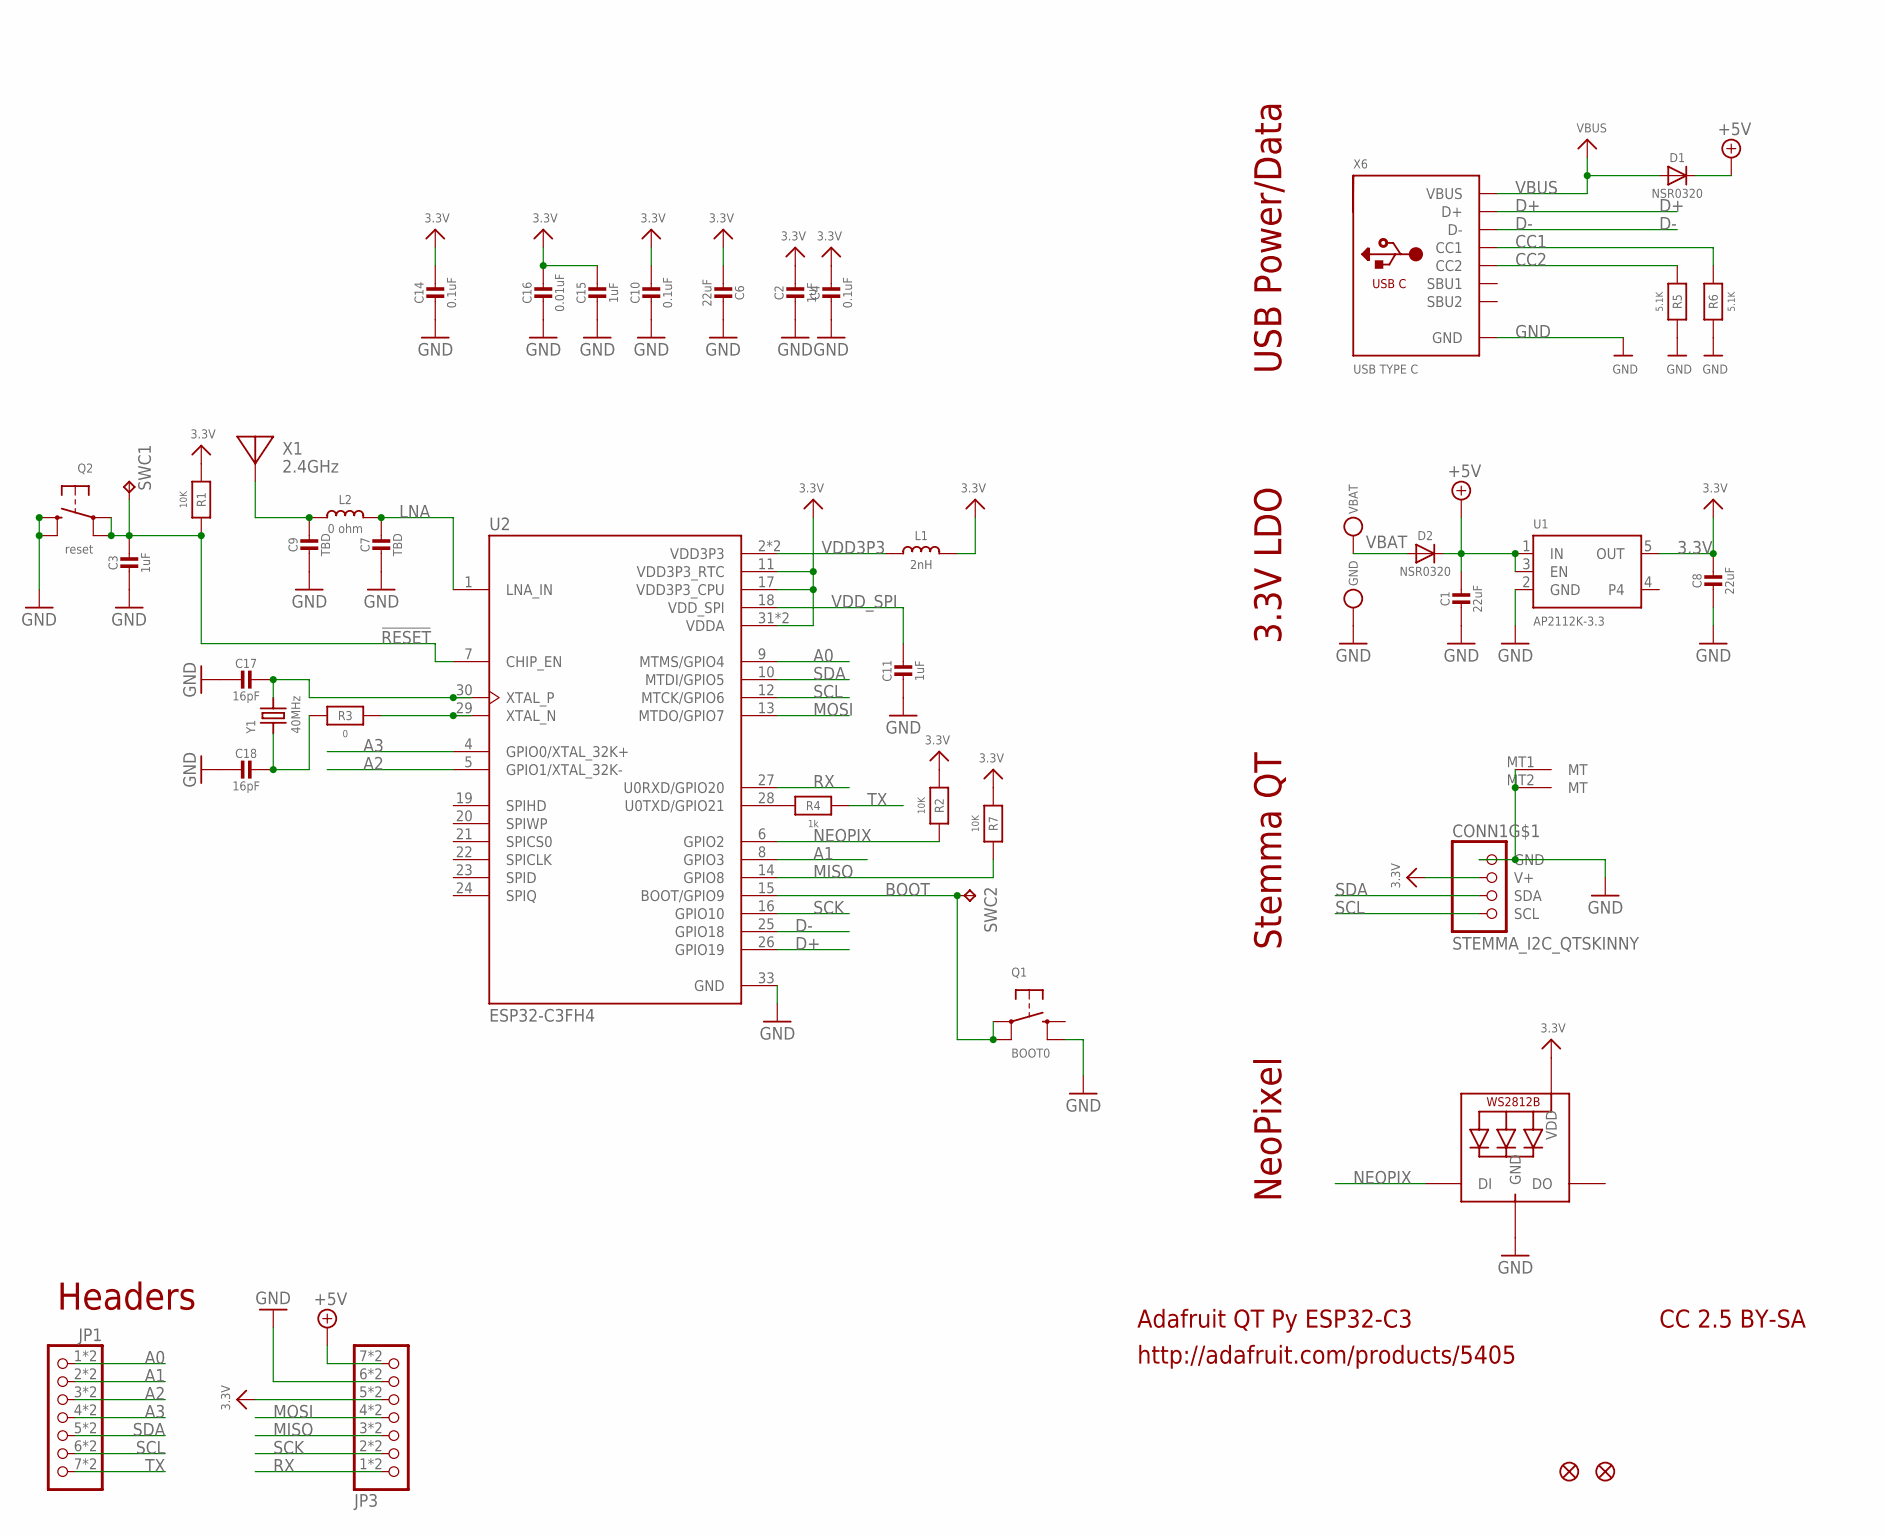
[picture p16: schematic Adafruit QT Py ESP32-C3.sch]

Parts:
C1, C6, C8: 22uF; 0805-NO
C2, C3, C11, C15: 1uF; _0402NO
C4, C10, C14: 0.1uF; _0402NO
C7, C9: TBD; _0402NO
C16: 0.01uF; _0402NO
C17, C18: 16pF; _0402NO
CONN1: STEMMA_I2C_QTSKINNY; JST_SH4_SKINNY
D1, D2: NSR0320; SOD-323_MINI
GND: TESTPOINT_MINUS; TESTPOINT_MINUS_1X3MM
JP1, JP3: HEADER-1X7_CASTEL; 1X07_CASTEL
L1: 2nH; _0402
L2: 0 ohm; _0402
LED1: WS2812B_SK6805_1515; SK6805_1515
Q1: BOOT0; BTN_KMR2_4.6X2.8
Q2: reset; BTN_KMR2_SLIM
R1, R2: 10K; _0402NO
R3: 0; _0402NO
R4: 1k; _0402NO
R5, R6: 5.1K; _0402NO
R7: 10K; _0603MP_TWO6MIL
SWC1, SWC2: TPB1,27; B1,27
U1: AP2112K-3.3; SOT23-5
U2: ESP32-C3FH4; QFN32_5MM
U$6, U$8: FIDUCIAL_1MM
VBAT: TESTPOINT_PLUS13; TESTPOINT_PLUS_1X3MM
X1: 2.4GHz; ANT_2450AT18B100
X6: USB TYPE C; USB_C_CUSB31-CFM2AX-01-X
Y1: 40MHz; CRYSTAL_2X1.6

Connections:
3.3V: C2.1, C4.1, C6.1, C8.1, C10.1, C14.1, C15.1, C16.1, CONN1.2 (V+), JP3.5, JP3.5C (5), L1.1, LED1.2 (VDD), R1.1, R2.1, R7.1, U1.5 (OUT), U2.11 (VDD3P3_RTC), U2.17 (VDD3P3_CPU), U2.31 (VDDA), U2.32 (VDDA)
!RESET: C3.1, Q2.A, Q2.A' (P1), R1.2, SWC1.TP, U2.7 (CHIP_EN)
+5V: C1.1, D1.C, D2.C, JP3.7, JP3.7C (7), U1.1 (IN), U1.3 (EN)
A0: JP1.1, JP1.1C (1), U2.9 (MTMS/GPIO4)
A1: JP1.2, JP1.2C (2), U2.8 (GPIO3)
A2: JP1.3, JP1.3C (3), U2.5 (GPIO1/XTAL_32K-)
A3: JP1.4, JP1.4C (4), U2.4 (GPIO0/XTAL_32K+)
BOOT: Q1.A, Q1.A' (P1), SWC2.TP, U2.15 (BOOT/GPIO9)
CC1: R6.2, X6.A5 (CC1)
CC2: R5.2, X6.B5 (CC2)
D+: U2.26 (GPIO19), X6.A6 (D+), X6.B6 (D+)
D-: U2.25 (GPIO18), X6.A7 (D-), X6.B7 (D-)
GND: C1.2, C2.2, C3.2, C4.2, C6.2, C7.2, C8.2, C9.2, C10.2, C11.2, C14.2, C15.2, C16.2, C17.2, C18.2, CONN1.1 (GND), CONN1.MT1 (MT), CONN1.MT2 (MT), GND.P$1, JP3.6, JP3.6C (6), LED1.4 (GND), Q1.B' (S1), Q2.B (S), Q2.B' (S1), R5.1, R6.1, U1.2 (GND), U2.33 (GND), X6.A1B12 (GND), X6.B1A12 (GND)
LNA: C7.1, L2.2, U2.1 (LNA_IN)
MISO: JP3.3, JP3.3C (3), R7.2, U2.14 (GPIO8)
MOSI: JP3.4, JP3.4C (4), U2.13 (MTDO/GPIO7)
unnamed: R4.1, U2.28 (U0TXD/GPIO21)
unnamed: C9.1, L2.1, X1.FP
unnamed: R3.2, U2.29 (XTAL_N)
unnamed: C17.1, U2.30 (XTAL_P), Y1.3 (2)
unnamed: C18.1, R3.1, Y1.1
NEOPIX: LED1.1 (DI), R2.2, U2.6 (GPIO2)
RX: JP3.1, JP3.1C (1), U2.27 (U0RXD/GPIO20)
SCK: JP3.2, JP3.2C (2), U2.16 (GPIO10)
SCL: CONN1.4 (SCL), JP1.6, JP1.6C (6), U2.12 (MTCK/GPIO6)
SDA: CONN1.3 (SDA), JP1.5, JP1.5C (5), U2.10 (MTDI/GPIO5)
TX: JP1.7, JP1.7C (7), R4.2
VBAT: D2.A, VBAT.P$1
VBUS: D1.A, X6.A4B9 (VBUS), X6.B4A9 (VBUS)
VDD3P3: L1.2, U2.2 (VDD3P3), U2.3 (VDD3P3)
VDD_SPI: C11.1, U2.18 (VDD_SPI)

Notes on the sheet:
Adafruit QT Py ESP32-C3
http://adafruit.com/products/5405
CC 2.5 BY-SA
NeoPixel
Stemma QT
3.3V LDO
USB Power/Data
Headers

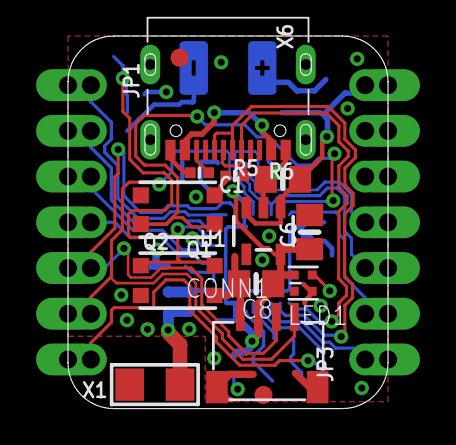
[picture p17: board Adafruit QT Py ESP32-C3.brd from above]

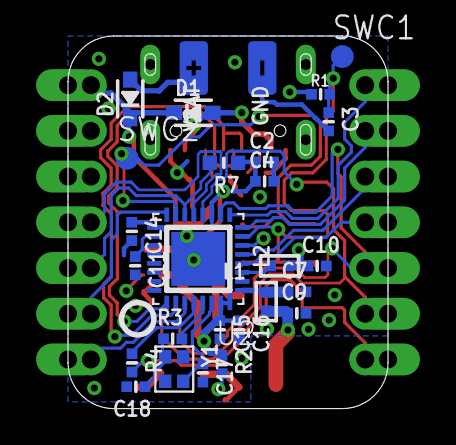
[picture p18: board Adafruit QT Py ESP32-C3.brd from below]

Board: 2 copper layers, 17.8 x 20.7 mm, 46 parts (29 on the bottom side), 31 nets.

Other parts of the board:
U$3: QTPYC3_TOP
U$12: PCBFEAT-REV-040
U$18: QTPYC3_BOT

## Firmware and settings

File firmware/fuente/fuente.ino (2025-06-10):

#include <SPI.h>
#include <Wire.h>
#include <Adafruit_GFX.h>
#include <Adafruit_SSD1306.h>
#include <RotaryEncoder.h>


// OLED
#define OLED_RESET     -1
#define SCREEN_ADDRESS 0x3C//78
#define SCREEN_WIDTH 128
#define SCREEN_HEIGHT 64


// Encoder KY-040
#define ENCODER_CLK 5
#define ENCODER_DT  6

#define LED_PIN 4

#define SDA_PIN 8
#define SCL_PIN 9

// MCP41050
#define CS_PIN 10 // Chip Select
#define SCLK_PIN 12 
#define MOSI_PIN 11
#define MISO_PIN 13

#define V_MAX 97.8
#define V_MID 37.3
#define V_MIN 23.3
 
RotaryEncoder encoder(ENCODER_CLK, ENCODER_DT, RotaryEncoder::LatchMode::FOUR0);
SPIClass SPIbus(FSPI);  // Puedes usar VSPI/HSPI/FSPI según el core

TwoWire I2CBus = TwoWire(0); // Puedes usar Wire también si solo usas uno
Adafruit_SSD1306 display(SCREEN_WIDTH, SCREEN_HEIGHT, &I2CBus, OLED_RESET);

float v_out = 23.3;



volatile int currentValue = 50;  // Valor de salida (0–100%)
int lastClkState;


void updateOutput(int percent);
float calcularVoltaje(int x);

void IRAM_ATTR checkEncoder() 
{
  encoder.tick();  // Debe llamarse en interrupción
}

void setup()
{
  Serial.begin(9600);
  while(!Serial);


  I2CBus.begin(SDA_PIN, SCL_PIN);
  SPIbus.begin(SCLK_PIN, MISO_PIN, MOSI_PIN, CS_PIN);
  
  pinMode(CS_PIN, OUTPUT);
  digitalWrite(CS_PIN, HIGH);
  
  pinMode(LED_PIN,OUTPUT);
  digitalWrite(LED_PIN,HIGH);
  
  pinMode(CS_PIN, OUTPUT);
  digitalWrite(CS_PIN, HIGH);
  
  pinMode(ENCODER_CLK, INPUT);
  pinMode(ENCODER_DT, INPUT);

   // Inicializar encoder
  attachInterrupt(digitalPinToInterrupt(ENCODER_CLK), checkEncoder, CHANGE);
  attachInterrupt(digitalPinToInterrupt(ENCODER_DT),  checkEncoder, CHANGE);

  Serial.println(F("Setup listo"));

  encoder.setPosition(currentValue);
  Serial.println(F("Encendiendo pantalla"));
  // OLED
  if (!display.begin(SSD1306_SWITCHCAPVCC, SCREEN_ADDRESS)) 
  {
    Serial.println(F("No se encontró pantalla OLED"));
  
  }

  // OLED
  display.begin(SSD1306_SWITCHCAPVCC, SCREEN_ADDRESS);
  display.clearDisplay();
  display.setTextSize(2);
  display.setTextColor(SSD1306_WHITE);

  updateOutput(currentValue);


}

void loop() 
{
  encoder.tick(); // También debe llamarse en loop()

  static int lastPos = -1;
  int newPos = encoder.getPosition();

  if (newPos != lastPos) 
  {
    currentValue = constrain(newPos, 0, 100);
    v_out = calcularVoltaje(currentValue);
    v_out = int(v_out*100 + 0.5)/100.0; 
    updateOutput(currentValue);
    lastPos = newPos;
  }
}


void updateOutput(int percent) 
{
  int value = map(percent, 0, 100, 255, 0);
  Serial.println(F("updating value"));

  // Enviar a MCP41050
  digitalWrite(CS_PIN, LOW);
  SPIbus.transfer(0x11); // Comando para escribir
  SPIbus.transfer(value);
  digitalWrite(CS_PIN, HIGH);

  // Mostrar en pantalla OLED
  display.clearDisplay();
  display.setCursor(10, 20);
  display.print("P: ");
  display.print(percent);
  display.print("%");
  display.setCursor(10, 40);
  display.print("V: ");
  display.print(v_out);
  
  display.display();

  // Serial debug
  Serial.print("Valor de salida: ");
  Serial.print(percent);
  Serial.print("% ; Voltaje estimado : ");
  Serial.println(v_out);
}

float calcularVoltaje(int x) {
  //return 0.000003238 * pow(x, 3) - 0.0005 * pow(x, 2) + 0.0911 * x + 23.3007;
  return 23.3 * exp(0.014617 * x);
}

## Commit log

2025-06-10 adding pcb and doc files
    [Adafruit QT Py ESP32-C3.brd, Adafruit QT Py ESP32-C3.kicad_pcb, Adafruit QT Py ESP32-C3.kicad_sch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]
2025-06-10 adding files to repo
    [fuente_regulable-B_Cu.gbl, fuente_regulable-B_Mask.gbs, fuente_regulable-B_Paste.gbp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]
2025-06-10 adding firmware code
    [Banana simple.SLDASM, Banana simple_negro.SLDASM, Banana simple_rojo.SLDASM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]
2025-06-10 adding bom
    [fuente_regulable_bom.csv]
2025-09-01 updating 3d models
    [Banana simple.SLDASM, Banana simple_negro.SLDASM, Banana simple_rojo.SLDASM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]
2025-09-01 adding step files for power supply FuRe
    [fure_base.step, fure_cara.step, fure_tapa.step]

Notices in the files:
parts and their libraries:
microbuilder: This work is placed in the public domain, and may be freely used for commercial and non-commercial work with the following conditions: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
